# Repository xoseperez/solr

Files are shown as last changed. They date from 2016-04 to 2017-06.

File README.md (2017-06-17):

# Solr

The **Solr digital wrist watch** is a clock that won’t work without a battery but it will neither work without sun. Even more: the vintage display is really cool but it’s hard to read outdoors. A complete nonsense.

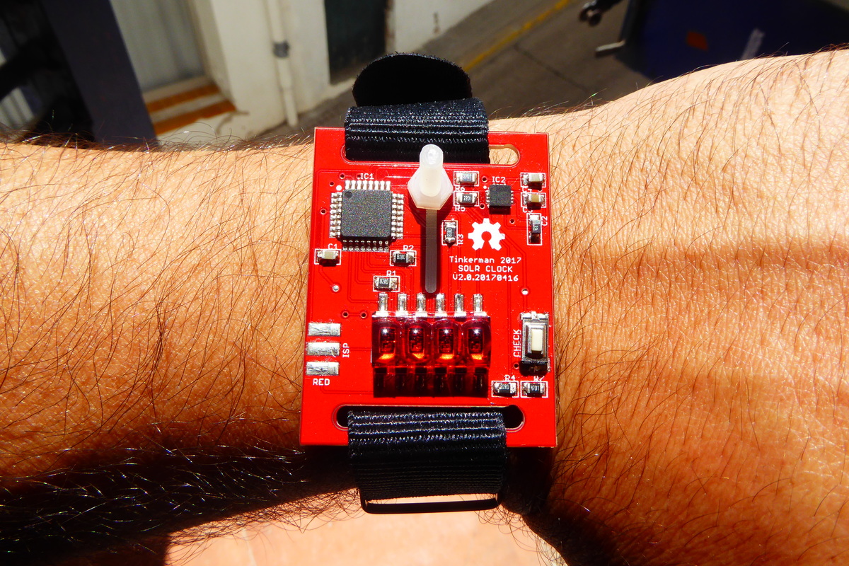
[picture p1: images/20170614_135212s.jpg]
Solr Watch


Check my **blog post** to know more about it: [Solr: digital wrist watch](http://tinkerman.cat/solr-digital-wrist-watch/)

## Hardware

I strongly recommend to find some provider that can assembly at least the HMC5883L, it's a really hard to chip to solder manually. The rest of the components are quite easy to do.

### BOM as exported from Eagle

|Part|Value|Package|Buy|
|---|---|---|---|
|BATT||CR2032-SMD|.|
|C1|100nf|C0805|.|
|C2|4.7uf|AVX-A|.|
|C3|220nf|C0805|.|
|C4|100nf|C0805|.|
|CHECK||BTN_CK_KSS|[Aliexpress](http://s.click.aliexpress.com/e/MrBaM7q)|
|IC1|ATMEGA328P-AU-TQFP32|TQFP32-0.8-7X7MM|[Aliexpress](http://s.click.aliexpress.com/e/Y3FMzZV)|
|IC2|HMC5883L|PLCC16-0.5-3X3MM|[Aliexpress](http://s.click.aliexpress.com/e/bIAm2zB) / [Ebay](https://rover.ebay.com/rover/1/711-53200-19255-0/1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)|
|LED1|HP QDSP-6064||[Ebay](https://rover.ebay.com/rover/1/1185-53479-19255-0/1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)|
|R1|82R|R0805|.|
|R2|82R|R0805|.|
|R3|82R|R0805|.|
|R4|82R|R0805|.|
|R5|2.2K|R0805|.|
|R6|2.2K|R0805|.|
|R7|4.7K|R0805|.|

## Firmware

Check the blog post above to connect an AVR programmer to the board.

The project is ready to be build using [PlatformIO](http://www.platformio.org).
Please refer to their web page for instructions on how to install the builder.
Once installed:

```bash
> cd code
> pio run -e dev
> avrdude -v -p atmega328p -C avrdude.conf -c usbasp -Pusb -U flash:w:.pioenvs/dev/firmware.hex:i

```

Library dependencies are automatically managed via PlatformIO Library Manager.

Using PlatformIO to flash the board will probably result in an error since, by default, PlatformIO forces the -D flag on the compiler that skips the erasing process prior to flash the new project, then the verification will likely fail because out-of-boundaries memory positions will contain garbage data. That's why I'm compiling the code with PlatfomIO and flashing it directly using avrdude.

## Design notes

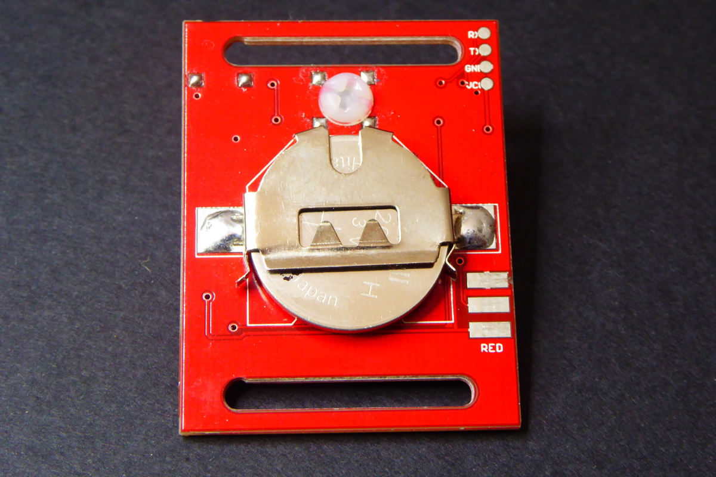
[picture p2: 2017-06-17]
images/20170614_134636s.jpg

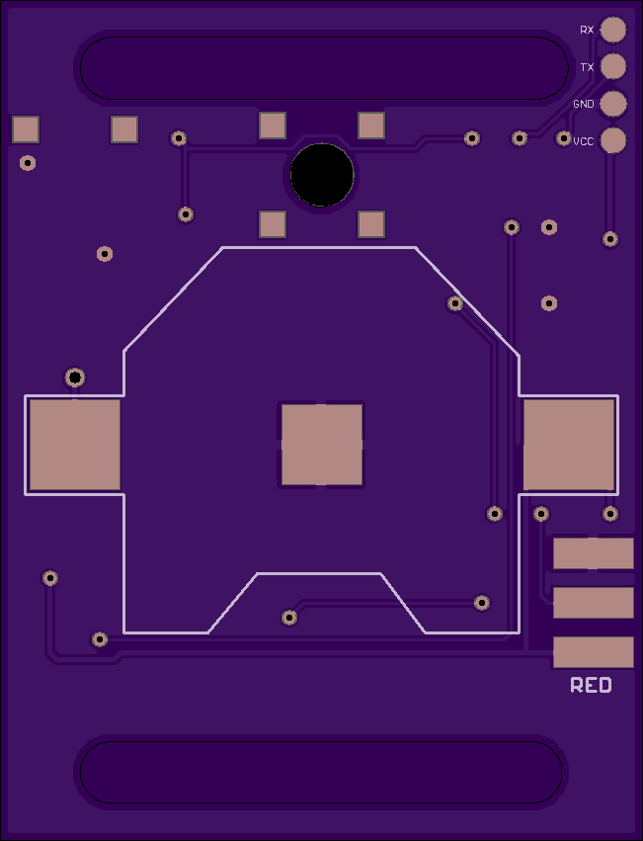
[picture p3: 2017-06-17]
images/solr-v2.1-bottom.png

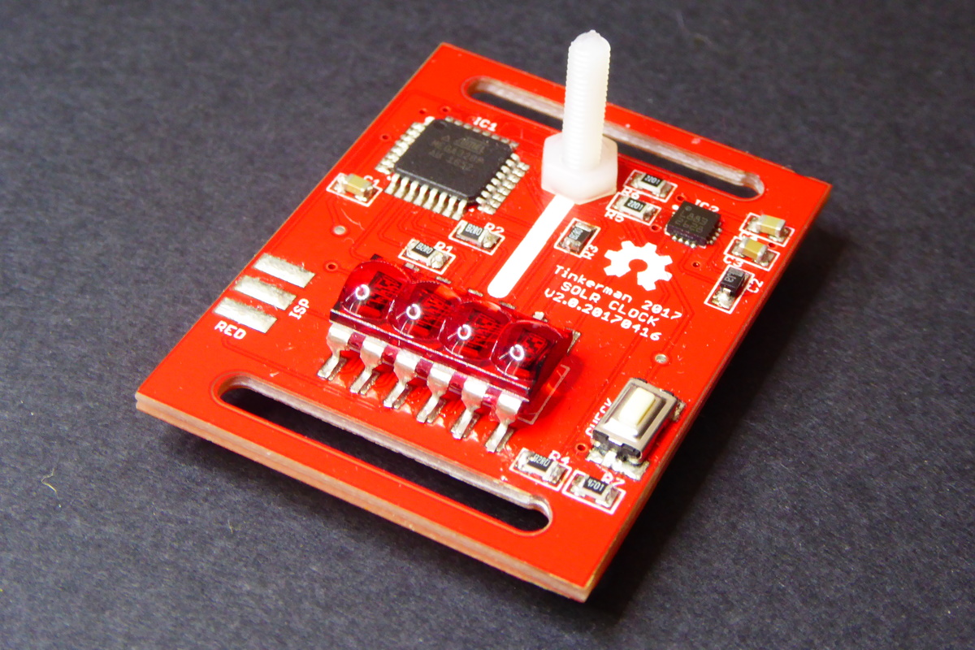
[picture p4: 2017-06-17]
images/20170614_134629s.jpg

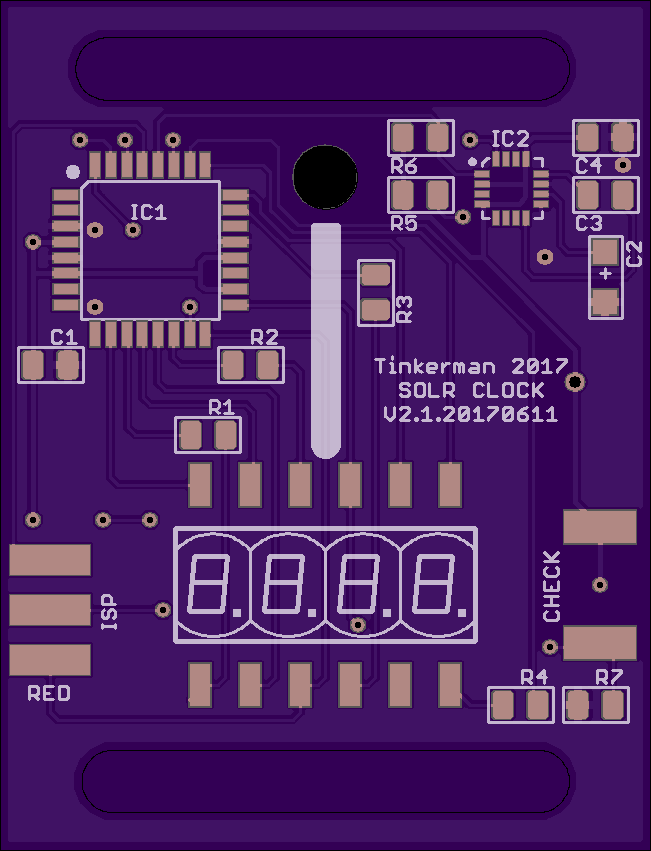
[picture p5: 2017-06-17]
images/solr-v2.1-front.png

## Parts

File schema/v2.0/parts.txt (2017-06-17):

Partlist

Exported from solr.brd at 4/16/17 9:12 PM

EAGLE Version 8.0.1 Copyright (c) 1988-2017 Autodesk, Inc.

Assembly variant: 

Part     Value                Package              Library              Position (mil)        Orientation

BATT                          CR2032-SMD           xose                 (650 800)             MR180
C1       100nf                C0805                Seeed-Capacitor-2016 (100 970)             R90
C2       4.7uf                AVX-A                Seeed-Capacitor-2016 (1210 1145)           R270
C3       220nf                C0805                Seeed-Capacitor-2016 (1210 1310)           R270
C4       100nf                C0805                Seeed-Capacitor-2016 (1210 1425)           R270
CHECK                         BTN_CK_KSS           adafruit             (1200 530)            R90
IC1      ATMEGA328P-AU-TQFP32 TQFP32-0.8-7X7MM     Seeed-IC-2016        (300 1200)            R0
IC2      HMC5883L             PLCC16-0.5-3X3MM     Seeed-Sensor-2016    (962.5 1262.5)        R0
J1       ISP                  2X3EDGE              xose                 (100 480)             R270
JP1                           1X04_SMD_ROUND_PADS  xose                 (60 1415)             MR90
LED1     5082-7414            5082-7414            xose                 (400 380)             R0
R1       220R                 R0805                Seeed-Resistor-2016  (415 830)             R90
R2       220R                 R0805                Seeed-Resistor-2016  (500 970)             R90
R3       220R                 R0805                Seeed-Resistor-2016  (750 1115)            R0
R4       220R                 R0805                Seeed-Resistor-2016  (1040 290)            R90
R5       2.2K                 R0805                Seeed-Resistor-2016  (840 1310)            R270
R6       2.2K                 R0805                Seeed-Resistor-2016  (840 1425)            R270
R7       4.7K                 R0805                Seeed-Resistor-2016  (1190 290)            R90
U$1      M3_WELDING_NUTFLAT   M3_WELDING_NUT_FLAT  xose                 (650 1345)            MR0
U$2      M3_WELDING_NUTSTAND  M3_WELDING_NUT_STAND xose                 (1150 1437.5)         MR0

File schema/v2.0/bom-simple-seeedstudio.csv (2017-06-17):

Part/Designator | Manufacture Part Number/Seeed SKU | Quantity
IC1 | 310010049 | 1
IC2 | 314040002 | 1

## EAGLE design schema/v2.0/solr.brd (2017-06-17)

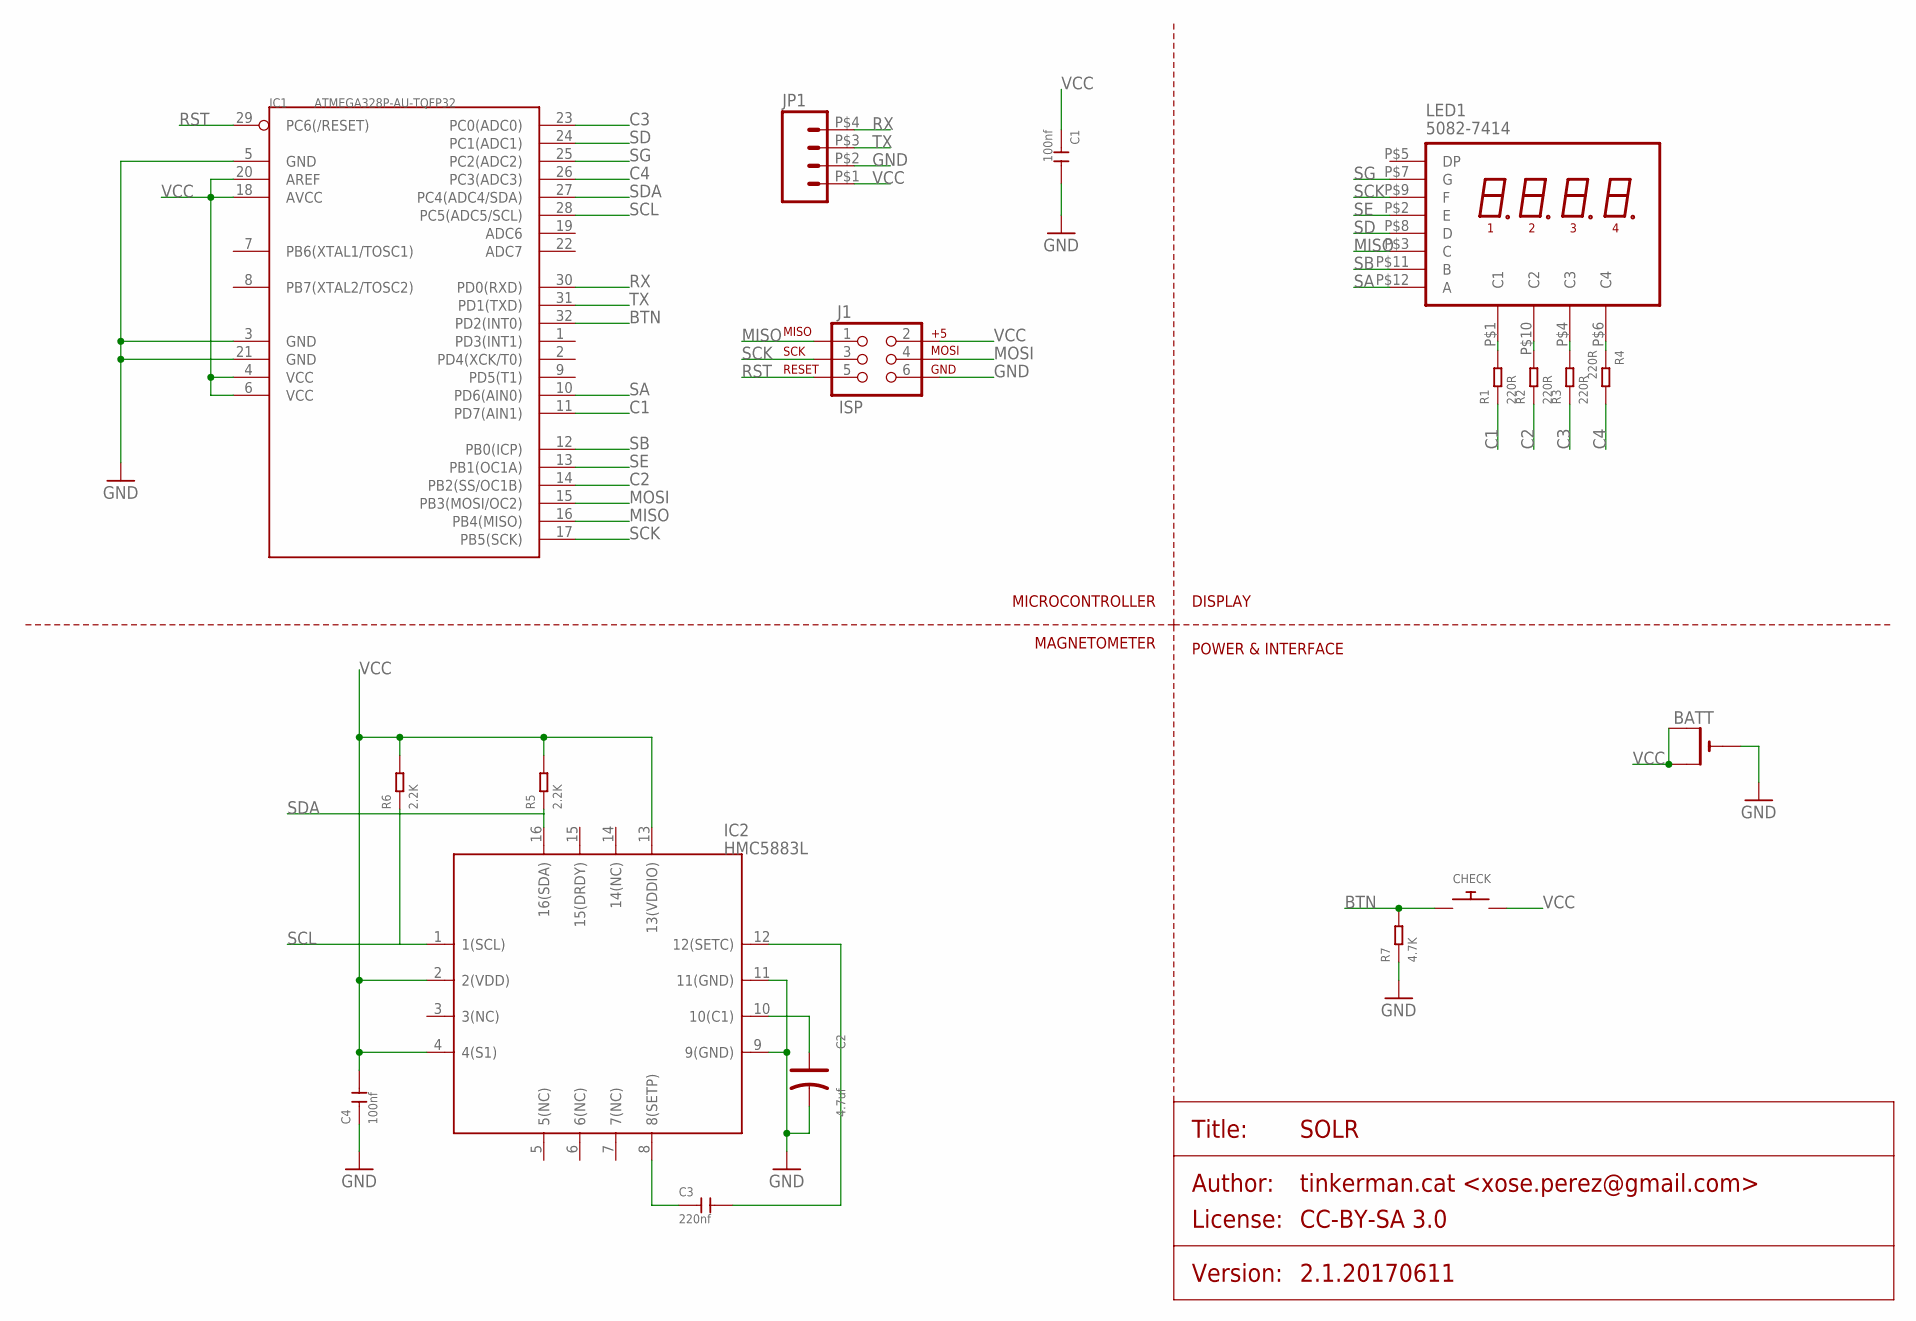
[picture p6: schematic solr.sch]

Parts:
BATT: CR2032SMT; CR2032-SMD
C1, C4: 100nf; C0805
C2: 4.7uf; AVX-A
C3: 220nf; C0805
CHECK: SWITCH_PUSHBUTTONC&K_KSS; BTN_CK_KSS
IC1: ATMEGA328P-AU-TQFP32; TQFP32-0.8-7X7MM
IC2: HMC5883L; PLCC16-0.5-3X3MM
J1: ISP; 2X3EDGE
JP1: M04SMD_ROUND_PADS; 1X04_SMD_ROUND_PADS
LED1: 5082-7414
R1, R2, R3, R4: 220R; R0805
R5, R6: 2.2K; R0805
R7: 4.7K; R0805

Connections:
BTN: CHECK.P$1, IC1.32 (PD2(INT0)), R7.2
C1: IC1.11 (PD7(AIN1)), R1.1
C2: IC1.14 (PB2(SS/OC1B)), R2.1
C3: IC1.23 (PC0(ADC0)), R3.1
C4: IC1.26 (PC3(ADC3)), R4.2
GND: BATT.-, C1.2, C2.-, C4.1, IC1.3 (GND), IC1.5 (GND), IC1.21 (GND), IC2.9 (9(GND)), IC2.11 (11(GND)), J1.6, JP1.P$2 (2), R7.1
MISO: IC1.16 (PB4(MISO)), J1.1, LED1.P$3 (C)
MOSI: IC1.15 (PB3(MOSI/OC2)), J1.4
unnamed: LED1.P$1 (C1), R1.2
unnamed: C3.1, IC2.8 (8(SETP))
unnamed: LED1.P$10 (C2), R2.2
unnamed: LED1.P$4 (C3), R3.2
unnamed: LED1.P$6 (C4), R4.1
unnamed: C3.2, IC2.12 (12(SETC))
unnamed: C2.+, IC2.10 (10(C1))
RST: IC1.29 (PC6(/RESET)), J1.5
RX: IC1.30 (PD0(RXD)), JP1.P$4 (4)
SA: IC1.10 (PD6(AIN0)), LED1.P$12 (A)
SB: IC1.12 (PB0(ICP)), LED1.P$11 (B)
SCK: IC1.17 (PB5(SCK)), J1.3, LED1.P$9 (F)
SCL: IC1.28 (PC5(ADC5/SCL)), IC2.1 (1(SCL)), R6.1
SD: IC1.24 (PC1(ADC1)), LED1.P$8 (D)
SDA: IC1.27 (PC4(ADC4/SDA)), IC2.16 (16(SDA)), R5.1
SE: IC1.13 (PB1(OC1A)), LED1.P$2 (E)
SG: IC1.25 (PC2(ADC2)), LED1.P$7 (G)
TX: IC1.31 (PD1(TXD)), JP1.P$3 (3)
VCC: BATT.+$1 (+), BATT.+$2 (+1), C1.1, C4.2, CHECK.P$2, IC1.4 (VCC), IC1.6 (VCC), IC1.18 (AVCC), IC1.20 (AREF), IC2.2 (2(VDD)), IC2.4 (4(S1)), IC2.13 (13(VDDIO)), J1.2, JP1.P$1 (1), R5.2, R6.2

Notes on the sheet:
MICROCONTROLLER
DISPLAY
POWER & INTERFACE
MAGNETOMETER

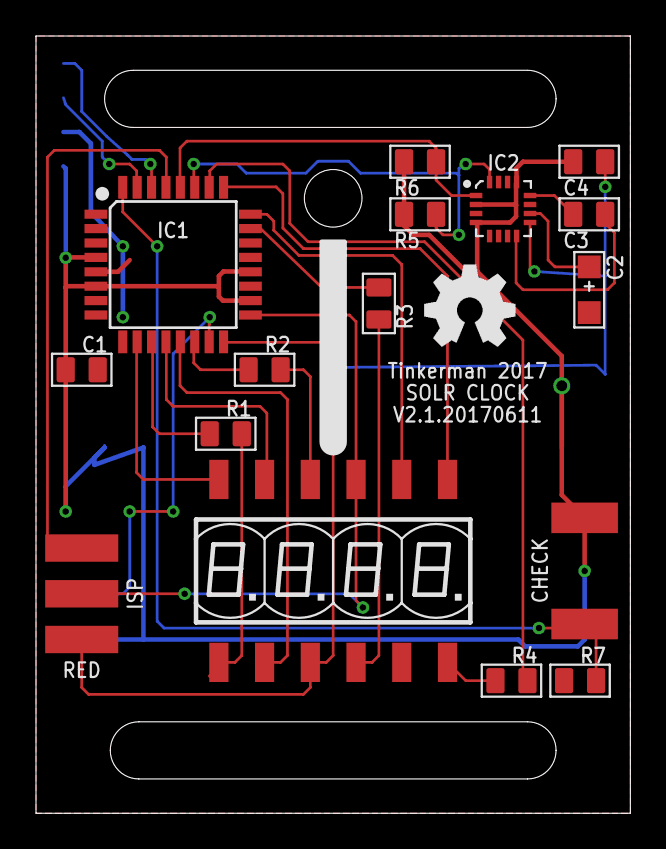
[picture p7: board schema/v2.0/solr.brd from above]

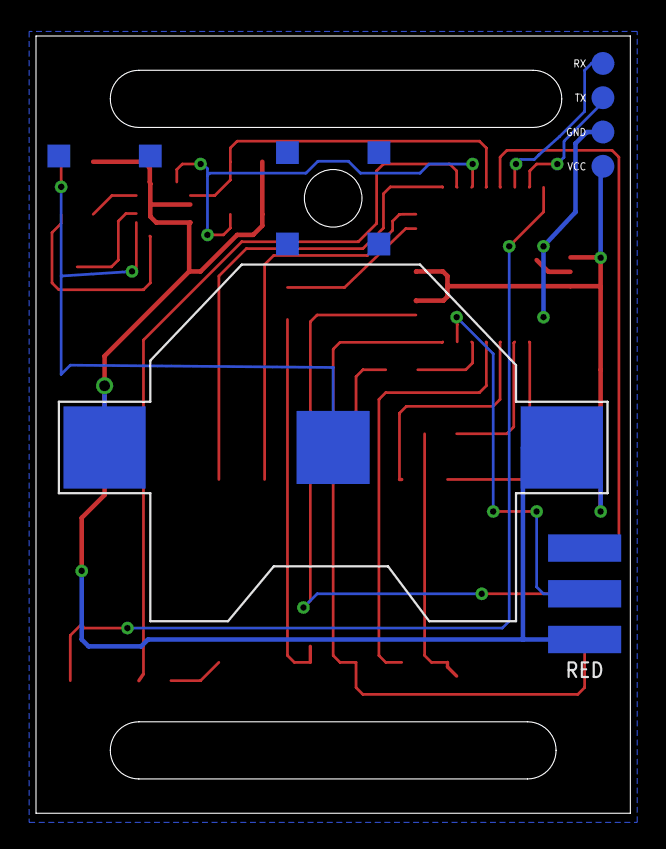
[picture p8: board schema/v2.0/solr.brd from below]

Board: 2 copper layers, 33.0 x 43.2 mm, 20 parts (4 on the bottom side), 27 nets.

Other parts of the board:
U$1: M3_WELDING_NUTFLAT; M3_WELDING_NUT_FLAT
U$2: M3_WELDING_NUTSTAND; M3_WELDING_NUT_STAND

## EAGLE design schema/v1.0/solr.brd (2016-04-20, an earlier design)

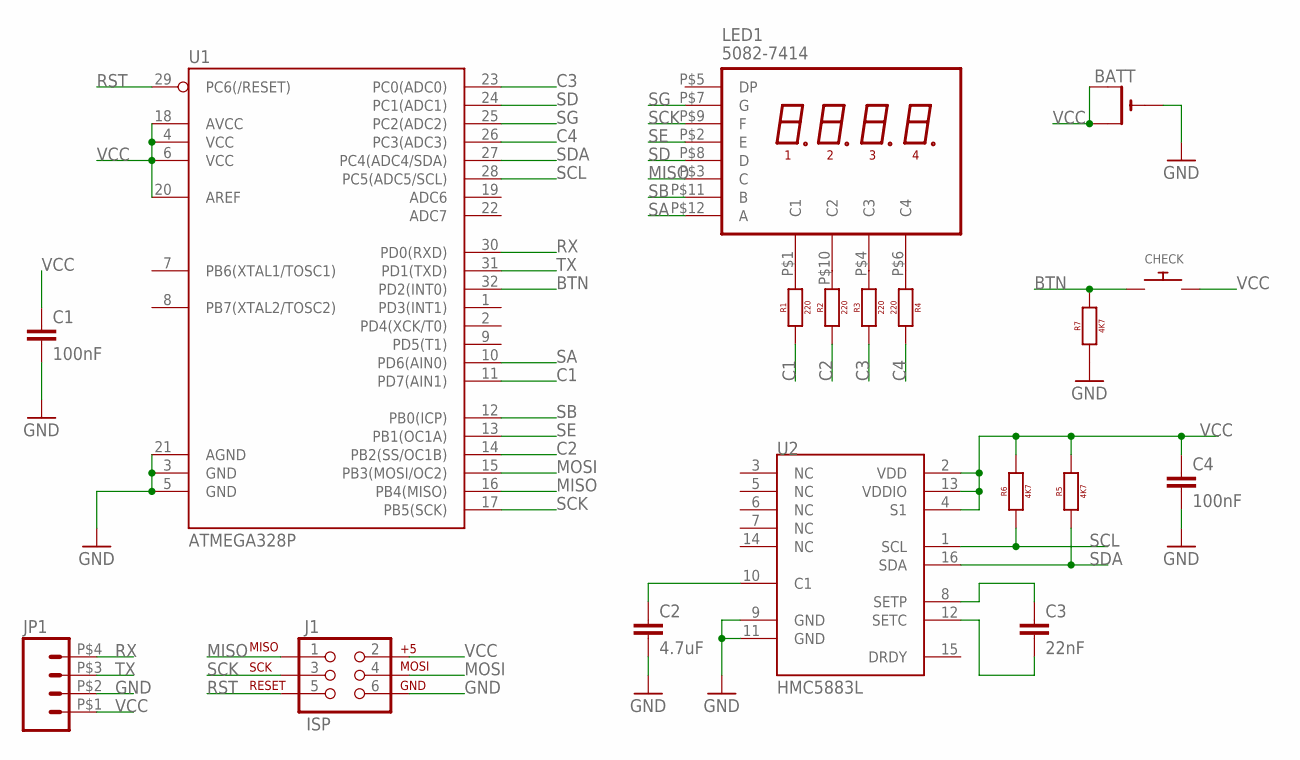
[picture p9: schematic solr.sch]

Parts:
BATT: CR2032SMT; CR2032-SMD
C1, C4: 100nF; 0805
C2: 4.7uF; 0805
C3: 22nF; 0805
CHECK: SWITCH_PUSHBUTTONC&K_KSS; BTN_CK_KSS
J1: ISP; 2X3EDGE
JP1: M04SMD_ROUND_PADS; 1X04_SMD_ROUND_PADS
LED1: 5082-7414
R1, R2, R3, R4: 220; 0805
R5, R6, R7: 4K7; 0805
U1: ATMEGA328P; TQFP32-08
U2: HMC5883L; 16LPCC

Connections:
BTN: CHECK.P$1, R7.2, U1.32 (PD2(INT0))
C1: R1.1, U1.11 (PD7(AIN1))
C2: R2.1, U1.14 (PB2(SS/OC1B))
C3: R3.1, U1.23 (PC0(ADC0))
C4: R4.2, U1.26 (PC3(ADC3))
GND: BATT.-, C1.2, C2.2, C4.2, J1.6, JP1.P$2 (2), R7.1, U1.3 (GND), U1.5 (GND), U1.21 (AGND), U2.9 (GND), U2.11 (GND)
MISO: J1.1, LED1.P$3 (C), U1.16 (PB4(MISO))
MOSI: J1.4, U1.15 (PB3(MOSI/OC2))
unnamed: LED1.P$1 (C1), R1.2
unnamed: C3.1, U2.8 (SETP)
unnamed: LED1.P$10 (C2), R2.2
unnamed: LED1.P$4 (C3), R3.2
unnamed: LED1.P$6 (C4), R4.1
unnamed: C3.2, U2.12 (SETC)
unnamed: C2.1, U2.10 (C1)
RST: J1.5, U1.29 (PC6(/RESET))
RX: JP1.P$4 (4), U1.30 (PD0(RXD))
SA: LED1.P$12 (A), U1.10 (PD6(AIN0))
SB: LED1.P$11 (B), U1.12 (PB0(ICP))
SCK: J1.3, LED1.P$9 (F), U1.17 (PB5(SCK))
SCL: R6.1, U1.28 (PC5(ADC5/SCL)), U2.1 (SCL)
SD: LED1.P$8 (D), U1.24 (PC1(ADC1))
SDA: R5.1, U1.27 (PC4(ADC4/SDA)), U2.16 (SDA)
SE: LED1.P$2 (E), U1.13 (PB1(OC1A))
SG: LED1.P$7 (G), U1.25 (PC2(ADC2))
TX: JP1.P$3 (3), U1.31 (PD1(TXD))
VCC: BATT.+$1 (+), BATT.+$2 (+1), C1.1, C4.1, CHECK.P$2, J1.2, JP1.P$1 (1), R5.2, R6.2, U1.4 (VCC), U1.6 (VCC), U1.18 (AVCC), U1.20 (AREF), U2.2 (VDD), U2.4 (S1), U2.13 (VDDIO)

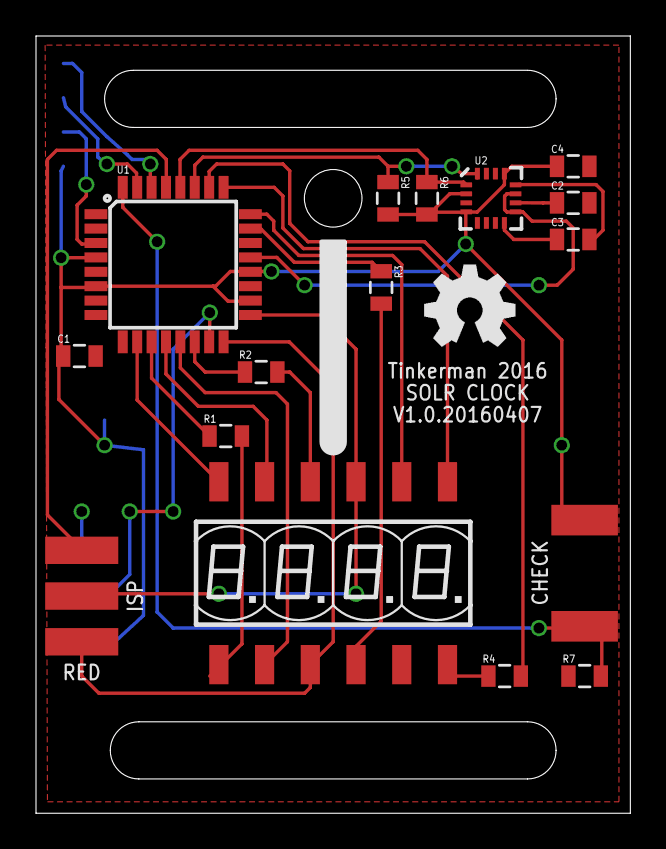
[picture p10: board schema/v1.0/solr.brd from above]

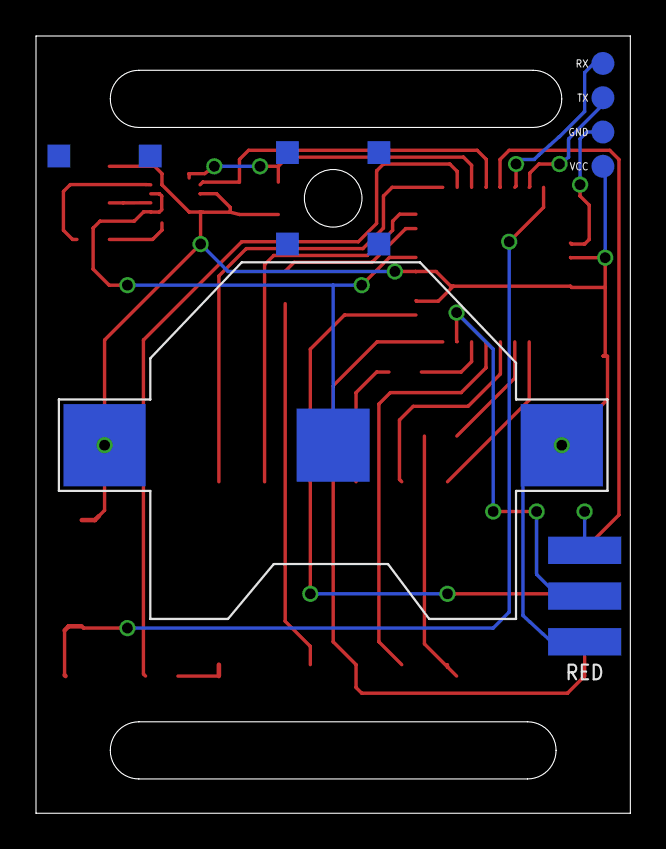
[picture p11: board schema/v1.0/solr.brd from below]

Board: 2 copper layers, 33.0 x 43.2 mm, 20 parts (4 on the bottom side), 27 nets.

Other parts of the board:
U$1: M3_WELDING_NUTFLAT; M3_WELDING_NUT_FLAT
U$2: M3_WELDING_NUTSTAND; M3_WELDING_NUT_STAND

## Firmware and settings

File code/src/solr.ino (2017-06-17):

/*

Solr
Open Source digital solar clock
Copyright (C) 2016 by Xose Pérez <xose dot perez at gmail dot com>

--------------------------------------------------------------------------------

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
--------------------------------------------------------------------------------

Pinout for HP Bubble Display (common cathode LEDs):

+--A--B--2--F--D--G--+
| 4 x 7 Segment + DP |
+--1--E--C--3--DP-4--+

MOSI (PIN 15, D11)
cannot be connected to LED display while programming

*/

#include "SevSeg.h"
#include "Compass.h"
#include "LowPower.h"

#define DEBUG 0

#define DIGITS 4
#define BRIGHTNESS 100

#define DIGIT_1 7
#define DIGIT_2 10
#define DIGIT_3 14
#define DIGIT_4 17

#define SEGMENT_A 6
#define SEGMENT_B 8
#define SEGMENT_C 12
#define SEGMENT_D 15
#define SEGMENT_E 9
#define SEGMENT_F 13
#define SEGMENT_G 16

#define DECIMAL_POINT 0 // NC
#define BUTTON_PIN 2
#define UPDATE_INTERVAL 1000
#define MIN_STABLE_COUNT 20

// Seven segments display object
SevSeg sevseg;

// HMC5883L class
Compass compass;

// Current time for display
unsigned long next_update;

void showText(char * text, unsigned long ms = 0) {
    unsigned long timeout = millis() + ms;
    while (millis() < timeout) {
        sevseg.DisplayString(text, 0);
    }
}

void showText(const char * text, unsigned long ms = 0) {
    showText((char *) text, ms);
}

int getBearing() {

    byte count = 0;
    int bearing = 0;

    while (count < MIN_STABLE_COUNT) {
       delay(20);
       int tmp = compass.getBearing();
       if (bearing == tmp) {
          count++;
       } else {
          bearing = tmp;
          count = 0;
       }
    }

    return bearing;

}

void updateDisplay(bool showTime = true) {

    // 0º is south, 90% west
    int bearing = getBearing();
    bearing = (bearing + 180) % 360;

    // 4 minutes per degree
    int minutes = 4 * bearing;
    int quarters = minutes / 15;
    int quarter = quarters % 4;
    int hour = (quarters - quarter) / 4;

    minutes = minutes % 60;
    minutes = (minutes / 5) * 5;
    hour = (hour + 2) % 24;

    char display[5];

    if (showTime) {
        sprintf(display, "%02i%02i", hour, minutes);
    } else {
        sprintf(display, "%03i!", bearing);
    }
    showText(display, 5000);

    #if DEBUG == 1
        Serial.print("Bearing: ");
        Serial.println(bearing);
        Serial.print("Hour: ");
        if (hour < 10) Serial.print("0");
        Serial.print(hour);
        Serial.print(":");
        if (minutes < 10) Serial.print("0");
        Serial.println(minutes);
        Serial.print("Display: ");
        Serial.println(display);
    #endif


}

void checkCalibration() {

   if (digitalRead(BUTTON_PIN) == HIGH) {
      delay(50);
      if (digitalRead(BUTTON_PIN) == HIGH) {

         // start calibration
         showText(" SET", 1000);
         showText("GAIN", 1000);
         compass.calibrate(HMC5883L_CALIBRATE_GAIN);
         showText("DONE", 1000);
         showText("OFFS", 1000);
         compass.calibrate(HMC5883L_CALIBRATE_OFFSET);
         showText("DONE", 1000);

      }
   }

}

void wakeUp() {
   // wake up
}

void setup() {

    // Initialize debug console
    #if DEBUG == 1
        Serial.begin(9600);
        while (!Serial);
    #endif

    // Configure seven segments display
    sevseg.Begin(
        COMMON_CATHODE, DIGITS,
        DIGIT_1, DIGIT_2, DIGIT_3, DIGIT_4,
        SEGMENT_A, SEGMENT_B, SEGMENT_C, SEGMENT_D, SEGMENT_E, SEGMENT_F, SEGMENT_G,
        DECIMAL_POINT
    );
    sevseg.SetBrightness(BRIGHTNESS);

    // Join I2C bus
    Wire.begin();

    // Test connection
    if (!compass.testConnection()) {
        showText("ERR1", 5000);
        while (true);
    }

    // Initialize compass
    compass.initialize();

    // Show welcome text
    showText("SOLR", 2000);

    // Define button interrupt
    pinMode(BUTTON_PIN, INPUT);

    // Check if calibration mode
    checkCalibration();

    // Next update time
    next_update = millis() + UPDATE_INTERVAL;

}

void loop() {

    // Allow wake up pin to trigger interrupt on low.
    attachInterrupt(digitalPinToInterrupt(BUTTON_PIN), wakeUp, HIGH);

    // Enter power down state with ADC and BOD module disabled.
    // Wake up when wake up pin is low.
    LowPower.powerDown(SLEEP_FOREVER, ADC_OFF, BOD_OFF);

    // Disable external pin interrupt on wake up pin.
    detachInterrupt(digitalPinToInterrupt(BUTTON_PIN));

    // Show
    updateDisplay(true);

}

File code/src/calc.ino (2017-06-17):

#include <math.h>

/*
    Equation of Time calculation
    *** No guarantees are implied. Use at your own risk ***

    Written by Del Smith, 2016-11-29

    Based on "Equation of time" WikiPedia article as of 2016-11-28
    (which describes angles in a bewildering mixture of degrees and radians)

    It appears to give a good result, but I make no claims for accuracy.
*/

// constants  (all angles as radians)
#define OMEGA       ( 2.0 * M_PI / 365.25 )
#define LAMBDA      ( 23.44 * M_PI / 180.0 )

// calculate the Equation of Time from 'day of year'
double equationOfTime(int day) {

    // the result is in seconds
    // add to the Mean Solar Time  (UTC + Longitude*240 sec.) to get Apparent Solar Time
    // D                                                          day of the year
    // A = W*(D+10)                                               angle of revolution (circular)
    // B = A + 0.0333*sin(W*(D-2))                                angle of revolution (elliptical)
    // C = ( A - atan[  tan(B) / cos (inclination) ] ) / 'pi'     angular correction
    // EOT = 43200 × (C − int(C+0.5))                             Equation of Time in seconds

    double alpha = OMEGA * ( ( day + 10 ) % 365 );                          // angle in (mean) circular orbit, solar year starts 21. Dec
    double beta = alpha + 0.0333 * sin( OMEGA * ( ( day - 2 ) % 365 ) );    // angle in elliptical orbit, from perigee 3. Jan (radians)
    double gamma = ( alpha - atan( tan(beta) / cos(LAMBDA))) / M_PI;        // angular correction
    return ( 43200.0 * ( gamma - (int) ( gamma + 0.5 ) ) );                 // equation of time in seconds

}

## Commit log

2016-04-20 Using helscream HMC5883L calibration code with Rowberg's lilbrary, platformio environments configuration
2016-04-20 First version of the PCB sent to fab
    [solr.brd, solr.sch]
2017-06-17 Version bump
    [bom-simple-seeedstudio.csv, solr.brd, solr.sch]

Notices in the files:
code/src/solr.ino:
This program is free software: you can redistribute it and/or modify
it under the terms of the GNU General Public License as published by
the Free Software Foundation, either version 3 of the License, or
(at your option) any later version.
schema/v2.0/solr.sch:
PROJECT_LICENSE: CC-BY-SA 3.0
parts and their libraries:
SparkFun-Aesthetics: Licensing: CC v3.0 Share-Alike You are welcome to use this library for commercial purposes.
